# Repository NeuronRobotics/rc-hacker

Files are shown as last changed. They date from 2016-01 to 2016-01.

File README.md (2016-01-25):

# rc-hacker

The RC Hacker combines the ESP8266 with 2 H bridges and
a MONO audio DAC/AMP and 5 GPIO. It is Programmed over
WIFI and is intended to be used to "Upcycle" old toys and
turn them into programable robots.

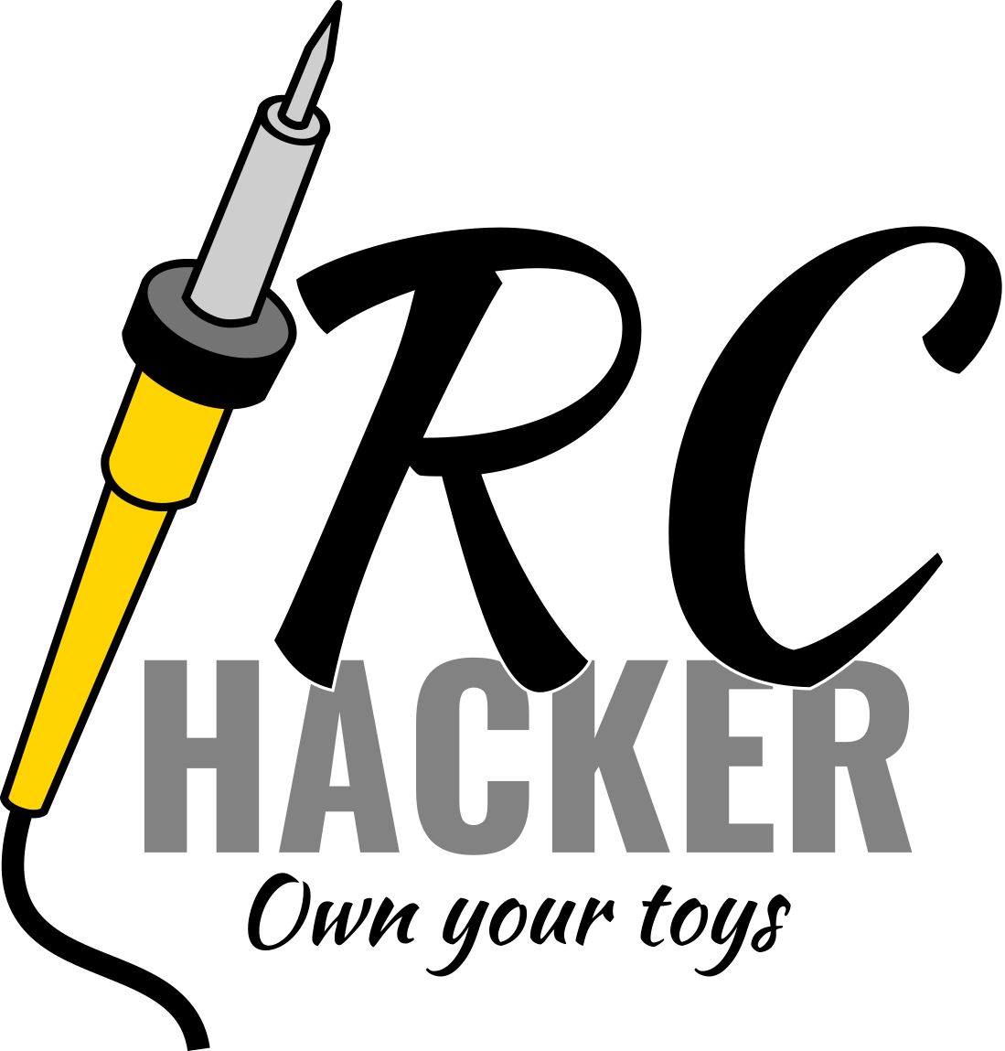
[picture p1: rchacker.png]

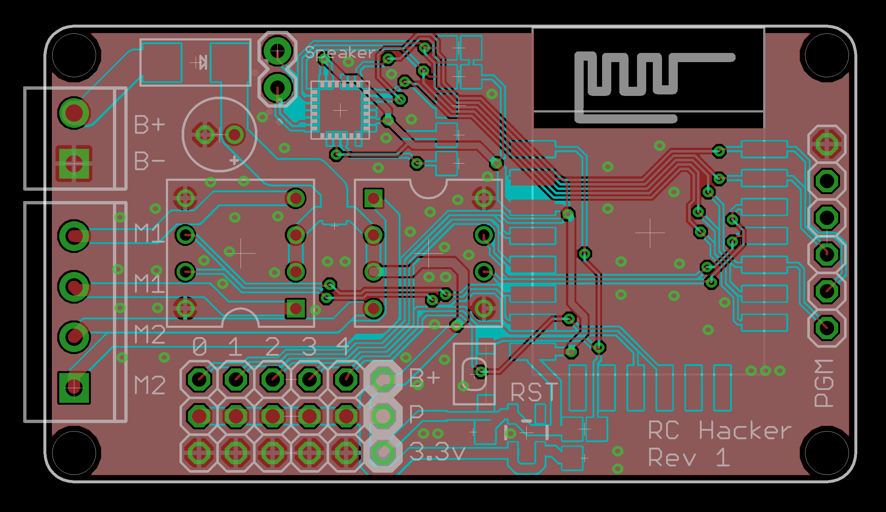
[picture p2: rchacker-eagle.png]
pcb


- ESP8266-12 wifi module
- Dual L9110 (800ma) DACs
- ALC5628 DAC+AMP
- Screw Terminals to attatch motors
- 5x 0.1" 3 pin headers for additional sensors/servos and 1 analog in.

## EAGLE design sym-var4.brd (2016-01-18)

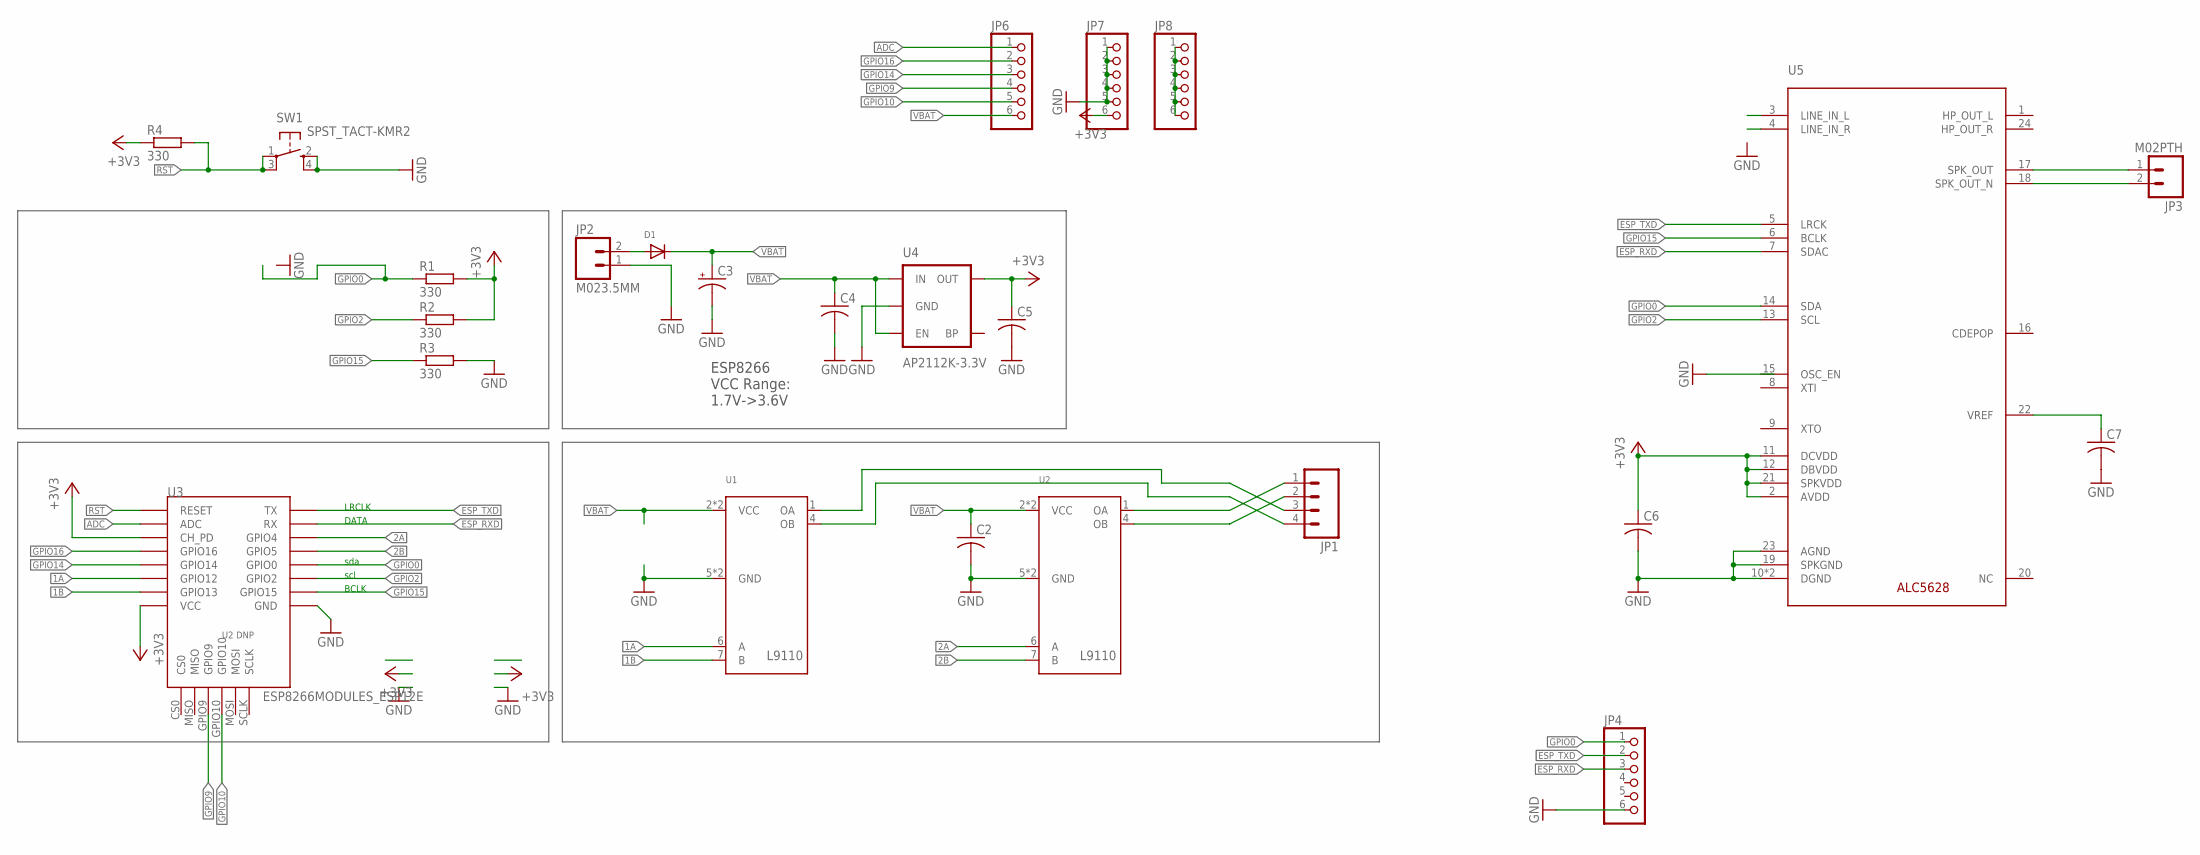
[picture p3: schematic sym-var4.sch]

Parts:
C2, C4, C5, C6, C7: C-USC0805; C0805
C3: CPOL-USE2-5; E2-5
D1: DIODESMA; SMADIODE
JP1: M04SCREW; SCREWTERMINAL-3.5MM-4
JP2: M023.5MM; SCREWTERMINAL-3.5MM-2
JP3: M02PTH; 1X02
JP4, JP6, JP7, JP8: PINHD-1X6; 1X06
R1, R2, R3, R4: 330; R0805
SW1: SPST_TACT-KMR2; KMR2
U1, U2: L9110; DIP8
U3: ESP8266MODULES_ESP12E
U4: AP2112K-3.3V; SOT23-5
U5: ALC5628; QFN24

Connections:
1A: U1.6 (A), U3.GPIO12
1B: U1.7 (B), U3.GPIO_13 (GPIO13)
2A: U2.6 (A), U3.GPIO4
2B: U2.7 (B), U3.GPIO5
+3V3: C5.1, C6.1, JP7.6, R1.2, R2.2, R4.1, U3.CH_PD, U3.VCC, U4.5 (OUT), U5.2 (AVDD), U5.11 (DCVDD), U5.12 (DBVDD), U5.21 (SPKVDD)
ADC: JP6.1, U3.ADC
ESP_RXD: JP4.3, U3.RX, U5.7 (SDAC)
ESP_TXD: JP4.2, U3.TX, U5.5 (LRCK)
GND: C2.2, C3.-, C4.2, C5.2, C6.2, C7.2, JP2.1, JP4.6, JP7.1, JP7.2, JP7.3, JP7.4, JP7.5, R3.2, SW1.2 (S), SW1.4 (S1), U1.5 (GND), U1.8 (GND), U2.5 (GND), U2.8 (GND), U3.GND, U4.2 (GND), U5.10 (DGND), U5.19 (SPKGND), U5.23 (AGND), U5.PAD (DGND)
GPIO0: JP4.1, R1.1, U3.GPIO0, U5.14 (SDA)
GPIO2: R2.1, U3.GPIO2, U5.13 (SCL)
GPIO9: JP6.4, U3.GPIO9
GPIO10: JP6.5, U3.GPIO10
GPIO14: JP6.3, U3.GPIO14
GPIO15: R3.1, U3.GPIO15, U5.6 (BCLK)
GPIO16: JP6.2, U3.GPIO_16 (GPIO16)
unnamed: JP1.1, U2.1 (OA)
unnamed: JP1.2, U2.4 (OB)
unnamed: JP1.4, U1.4 (OB)
unnamed: JP1.3, U1.1 (OA)
unnamed: D1.A, JP2.2
unnamed: C7.1, U5.22 (VREF)
unnamed: JP8.1, JP8.2, JP8.3, JP8.4, JP8.5, JP8.6
unnamed: JP3.1, U5.17 (SPK_OUT)
unnamed: JP3.2, U5.18 (SPK_OUT_N)
RST: R4.2, SW1.1, SW1.3 (P1), U3.RESET
VBAT: C2.1, C3.+, C4.1, D1.C, JP6.6, U1.2 (VCC), U1.3 (VCC), U2.2 (VCC), U2.3 (VCC), U4.1 (IN), U4.3 (EN)

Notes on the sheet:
U2 DNP
ESP8266 VCC Range: 1.7V->3.6V
LRCLK
DATA
BCLK
sda
scl

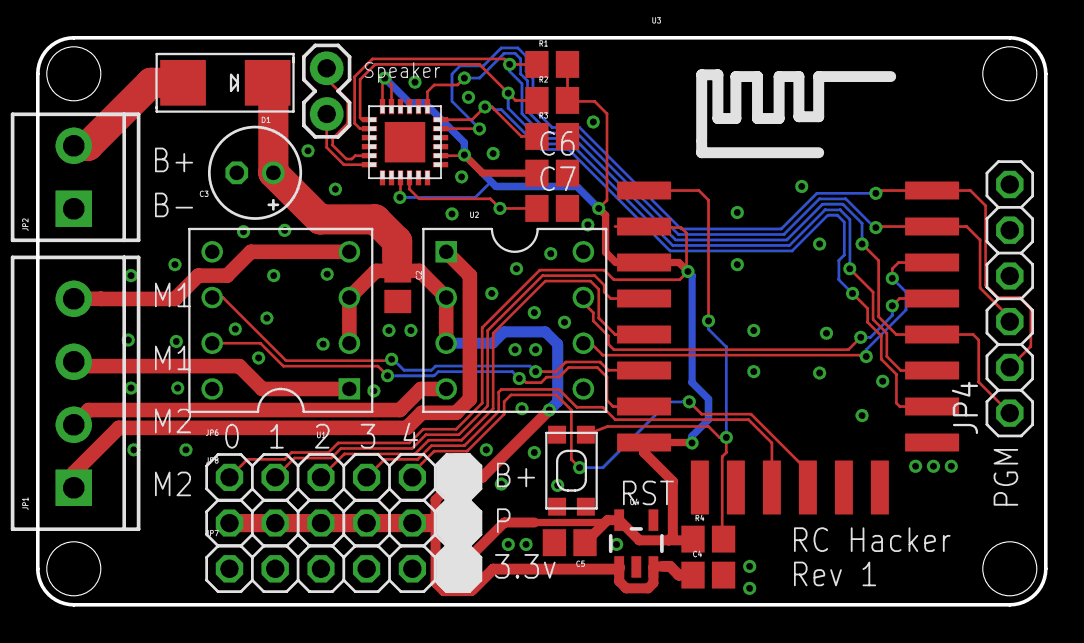
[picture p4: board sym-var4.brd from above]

Board: 2 copper layers, 56.0 x 31.5 mm, 24 parts (0 on the bottom side), 27 nets.

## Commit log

2016-01-17 Added PCB
    [sym-var4.brd, sym-var4.sch]
2016-01-17 Added Prog Connector
    [sym-var4.brd, sym-var4.sch]
2016-01-17 Added Board IMG
2016-01-18 Layout complete
    [sym-var4.brd, sym-var4.sch]

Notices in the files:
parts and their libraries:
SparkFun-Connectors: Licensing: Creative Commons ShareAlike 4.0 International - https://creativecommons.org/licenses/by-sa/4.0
